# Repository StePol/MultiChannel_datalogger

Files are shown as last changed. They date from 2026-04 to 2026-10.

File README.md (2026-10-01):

# Multi-Channel DataLogger (RPi Pico)

Tento projekt predstavuje robustný amatérsky datalogger postavený na mikrokontroléri Raspberry Pi Pico. Zariadenie monitoruje teplotu, vlhkosť, analógové napätia, binárne vstupy a stav batérie.

## 🚀 Kľúčové vlastnosti

- **Meranie prostredia:** SHT4x pre teplotu a relatívnu vlhkosť.
- **Viacbodové meranie teploty:** viacero senzorov DS18B20 na zbernici OneWire.
- **Analógové vstupy:** dva ADC vstupy 0–3,3 V.
- **Monitorovanie batérie:** meranie napätia batérie cez samostatný ADC vstup; táto časť hardvéru a firmware je stále vo vývoji.
- **Binárne vstupy:** štyri digitálne vstupy pre sledovanie logických stavov.
- **Záznam dát:** ukladanie meraní vo formáte CSV na microSD kartu.
- **Používateľské rozhranie:** SSD1306 OLED displej a rotačný enkodér s tlačidlom.
- **Presný čas:** externý RTC DS3231 synchronizovaný s interným RTC Raspberry Pi Pico.

## 🛠 Hardvérová konfigurácia
| Komponent | Pin (GP) | Funkcia |
|---|---|---|
| I2C0 (SDA/SCL) | 8 / 9 | OLED, RTC DS3231, SHT4x |
| SPI0 (SCK/MOSI/MISO) | 18/19/16 | SD Karta |
| SD Card CS | 17 | Chip Select pre SD |
| OneWire (DS18B20) | 22 | Teplotné senzory |
| Rotačný enkodér | 12 (CLK), 13 (DT) | Ovládanie menu (IRQ) |
| Tlačidlo enkodéra | 15 | Prepínanie režimov (Pauza/REC/Test) |
| Binárne vstupy | 2, 3, 4, 5 | Digitálne vstupy (Pull-up) |
| ADC Vstupy | 26, 27 | Analógové meranie |
| Battery Monitor | 28 (ADC), 21 (CTRL) | Meranie batérie cez tranzistory |
| Stavová LED | 14 | Signalizácia zápisu a chýb |

## 📁 Štruktúra projektu

- `firmware/` — MicroPython firmware pre Raspberry Pi Pico
- `hardware/schematic/` — KiCad projekt, schéma, PCB a lokálne knižnice
- `hardware/enclosure/` — podklady pre mechanickú konštrukciu
- `docs/data/` — ukážkové namerané dáta
- `docs/datasheet/` — technická dokumentácia použitých komponentov

Podrobnosti o firmware sú v [`firmware/README.md`](firmware/README.md).

Dokumentácia hardvéru a KiCad projektu je v
[`hardware/schematic/README.md`](hardware/schematic/README.md).

## ⚙️ Prevádzkové režimy

- **PAUZA** — zariadenie vykonáva merania a zobrazuje aktuálne hodnoty, ale nezapisuje ich na SD kartu. Enkodérom je možné zvoliť režim alebo interval záznamu.
- **REC** — namerané údaje sa ukladajú na SD kartu v nastavenom intervale. Pre každý záznam sa vytvorí nový CSV súbor s názvom `YYYYMMDD_HHMMSS.csv`.
- **TEST** — umožňuje prechádzať pripojené DS18B20 senzory a zobrazovať ich ROM ID a aktuálnu teplotu.
- **SYNC RTC** — synchronizuje externý RTC DS3231 s aktuálnym časom interného RTC Raspberry Pi Pico.

Interval záznamu je možné nastaviť od 5 do 300 sekúnd v krokoch po 5 sekúnd.

Podrobný popis ovládania a režimov je v
[`firmware/README.md`](firmware/README.md).

## 💾 Formát dát (CSV)

Pri spustení režimu **REC** sa vytvorí nový CSV súbor s názvom odvodeným
od aktuálneho dátumu a času. Do rovnakého súboru sa zapisuje až do
ukončenia režimu REC.

Pevná časť CSV hlavičky je:

```text
Cas,SHT_T,SHT_H,A1,A2,BAT,BIN,B1,B2,B3,B4
```
Za ňou firmware pridá ROM ID jednotlivých detegovaných DS18B20 senzorov
ako ďalšie stĺpce.
Príklad nameraných dát je v adresári [`docs/data/`](docs/data/).

## 🛡 Stabilita záznamu

- **Obsluha enkodéra cez IRQ:** enkodér je spracovávaný pomocou prerušenia.
- **Zápis na SD kartu:** po zápise dát firmware používa `flush()` a `uos.sync()` na prenesenie dát do súborového systému.
- **Správa pamäte:** firmware pravidelne používa garbage collection (`gc.collect()`).

## 🔌 Zapojenie

Detailné elektrické zapojenie je dostupné v KiCad projekte v
[`hardware/schematic/`](hardware/schematic/).

### 1. I2C zbernica (GP8, GP9)

Na spoločnej I2C zbernici sú pripojené:

- OLED displej SSD1306
- RTC DS3231
- senzor teploty a vlhkosti SHT4x

SDA a SCL vyžadujú pull-up rezistory. Pri použití hotových modulov je
potrebné overiť, či ich už moduly obsahujú.

### 2. microSD karta (SPI0)

microSD karta komunikuje s Raspberry Pi Pico cez SPI0:

| Signál | GPIO |
|---|---:|
| SCK | GP18 |
| MOSI | GP19 |
| MISO | GP16 |
| CS | GP17 |

Komunikačné signály microSD karty pracujú s logickými úrovňami 3,3 V.

### 3. OneWire (GP22)

DS18B20: Všetky senzory paralelne (Data na GP22, VCC na 3.3V, GND).
Pull-up: Medzi GP22 a 3.3V musí byť odpor 4.7kΩ.

### 4. Monitorovanie batérie

Napätie batérie sa meria pomocou ADC na GP28, pričom GP21 slúži na
ovládanie meracieho obvodu.

Hardvérové zapojenie a spôsob merania batérie sú stále vo vývoji a môžu
sa zmeniť. Aktuálne zapojenie je zdokumentované v KiCad schéme.

### 5. Ovládacie prvky

- **Enkodér:** CLK na GP12, DT na GP13; 10 nF kondenzátory slúžia na filtráciu zákmitov.
- **Tlačidlo enkodéra:** GP15, aktívne zopnutím proti GND s interným pull-up rezistorom.
- **Stavová LED:** GP14 cez 220 Ω rezistor.

## 📄 Licencia

Tento projekt je licencovaný pod [GNU GPL v3](LICENSE).

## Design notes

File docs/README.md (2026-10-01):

# Documentation

This directory contains supplementary documentation and example data for the
Multi-Channel DataLogger.

## Contents

| Directory | Description |
|---|---|
| `data/` | Example measurement data recorded by the datalogger |
| `datasheet/` | Datasheets and technical notes for hardware components |

## Measurement Data

The `data/` directory contains example CSV files generated by the firmware.
These files can be used to verify the data format or for testing data-processing
and visualization tools.

The current firmware records:

- SHT4x temperature and relative humidity
- multiple DS18B20 temperature sensors
- two analog inputs
- battery voltage
- four digital inputs

For the current CSV format and firmware operation, see
[`../firmware/README.md`](../firmware/README.md).

## Hardware Documentation

Component datasheets and related technical notes are stored in
[`datasheet/`](datasheet/).

The KiCad schematic and project-specific hardware documentation are located in
[`../hardware/schematic/`](../hardware/schematic/).

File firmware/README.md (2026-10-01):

# Firmware

This directory contains the software running on the Raspberry Pi Pico (RP2040).

## Hardware
- **Microcontroller:** Raspberry Pi Pico
- **Processor:** RP2040 (dual-core ARM Cortex-M0+)
- **Runtime:** MicroPython

## Development Environment
- **IDE:** Thonny
- **Language:** MicroPython

## Requirements
- Raspberry Pi Pico with MicroPython firmware installed
- Thonny IDE — [download here](https://thonny.org)

## Installation
1. Install MicroPython on the Pico:
   - Hold **BOOTSEL** button and connect Pico via USB
   - Copy the MicroPython `.uf2` file to the Pico drive
   - Pico restarts automatically
2. Open Thonny
3. Go to **Run → Select interpreter → MicroPython (Raspberry Pi Pico)**
4. Copy `.py` files to the Pico via Thonny

## Usage
- Open `main.py` in Thonny and click **Run**
- `main.py` is executed automatically on power-up

## Measured Parameters
- SHT4x temperature and relative humidity
- Multiple DS18B20 temperature sensors
- Two analog voltage inputs
- Battery voltage
- Four digital inputs

## Data Output
- CSV logging to microSD card
- Serial diagnostic output over USB
- Measurement status on SSD1306 OLED
- Logging interval selectable from 5 to 300 seconds
- CSV files use the timestamp format `YYYYMMDD_HHMMSS.csv`

## Operating Modes

The logger is controlled using the rotary encoder and its push button.

- **PAUZA** — measurements are displayed, but data is not written to the SD card.
- **REC** — measurements are periodically written to a CSV file.
- **TEST** — displays connected DS18B20 sensors, their ROM IDs and temperatures.
- **SYNC** — synchronizes the external DS3231 RTC with the current internal RTC time.

While in PAUZA mode, the rotary encoder selects `SyncRTC`, `TEST`, or a
logging interval from 5 to 300 seconds in 5-second steps.

## CSV Format

Each recording creates a new timestamped CSV file.

The fixed columns are:

```text
Cas,SHT_T,SHT_H,A1,A2,BAT,BIN,B1,B2,B3,B4
```

The ROM ID of each detected DS18B20 sensor is appended to the header as an
additional column.

An example recording is available in `../docs/data/`.

## Firmware Files

| File | Description |
|---|---|
| `main.py` | Main application and measurement loop |
| `ds3231.py` | DS3231 RTC driver |
| `sdcard.py` | microSD card driver |
| `sht4x.py` | SHT4x temperature/humidity driver |
| `ssd1306.py` | SSD1306 OLED driver |
| `TimeSet.py` | RTC utility |
| `TimeSyncPC.py` | RTC synchronization utility |

## Development Status

The battery measurement circuit and the corresponding firmware are still
under development and may change.

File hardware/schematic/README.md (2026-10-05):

# MultiChannel Datalogger – Hardware

This directory contains the KiCad hardware design files for the
MultiChannel Datalogger.

## KiCad version

The project is maintained with **KiCad 10**.

Open the project using:

`MultiChannel_datalogger.kicad_pro`

Do not open only the `.kicad_sch` file when working on the complete project.

## Project files

| File / Directory | Description |
|---|---|
| `MultiChannel_datalogger.kicad_pro` | KiCad project file |
| `MultiChannel_datalogger.kicad_sch` | Electrical schematic |
| `MultiChannel_datalogger.kicad_pcb` | PCB design |
| `MultiChannel_datalogger.pdf` | PDF export of the schematic |
| `MultiChannel_datalogger.csv` | Component/BOM export |
| `ADS1256_J3.md` | Tested ADS1256 24-bit ADC connection via J3 |
| `sym-lib-table` | Project symbol library configuration |
| `fp-lib-table` | Project footprint library configuration |
| `libraries/` | Project-specific symbols and footprints |

## Project libraries

Project-specific KiCad libraries are stored locally in the `libraries/`
directory so that the project does not depend on absolute paths on the
developer's computer.

The library tables use `${KIPRJMOD}` relative paths.

Currently included:

- Raspberry Pi / RP2040 symbol library
- Raspberry Pi Pico footprint
- RP2040 QFN-56 footprint
- HC49-US crystal footprint

## Portability

The repository is intended to contain all project-specific KiCad files
required to open the hardware design on another computer after cloning
the repository.

Standard symbols and footprints supplied with KiCad may still use the
standard KiCad libraries.

KiCad user-specific files, lock files, history and automatic backups are
excluded from Git.

## PCB status

The PCB project file is included, but the PCB layout has not yet been
designed.

## Generated files

`MultiChannel_datalogger.pdf` and `MultiChannel_datalogger.csv` are
generated from the schematic and should be updated when the schematic
changes significantly.

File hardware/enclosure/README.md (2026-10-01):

# Enclosure

This directory is reserved for the mechanical design of the
Multi-Channel DataLogger enclosure.

## Status

The enclosure has not been designed yet.

Mechanical dimensions, connector locations, display and control placement,
mounting points, and manufacturing method will be defined after the hardware
layout is sufficiently finalized.

## Planned Contents

The directory may later contain:

- source CAD files
- STEP or other exchange-format models
- STL files for 3D printing
- drawings with mechanical dimensions
- assembly documentation
- renders or photographs of the completed enclosure

## Design Considerations

The enclosure design should take into account:

- Raspberry Pi Pico and main PCB dimensions
- OLED display visibility
- rotary encoder and push-button access
- microSD card access
- sensor and measurement connectors
- USB access
- battery placement
- ventilation where required
- mounting and service access

Specific CAD software, manufacturing technology, materials, and print settings
will be selected when the enclosure design begins.

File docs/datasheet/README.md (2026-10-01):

# Datasheets

This directory contains component datasheets and technical notes used during
development of the Multi-Channel DataLogger.

## Sensors and RTC

| File | Component |
|---|---|
| `DS18B20.PDF` | DS18B20 digital temperature sensor |
| `DS3231.PDF` | DS3231 real-time clock |
| `SHT4X.PDF` | SHT4x temperature and humidity sensor |

## Battery Measurement

| File | Description |
|---|---|
| `MeranieNapatiaLiIonBaterie.md` | Project notes for Li-ion battery voltage measurement |
| `2N7000_BS170.PDF` | Vishay Siliconix datasheet covering the BS170 N-channel MOSFET used as Q2 |

The battery measurement circuit is still under development. Files in this
section are retained as design references and should not be interpreted as the
final component selection.

The current electrical design is documented in the KiCad project under
[`../../hardware/schematic/`](../../hardware/schematic/).

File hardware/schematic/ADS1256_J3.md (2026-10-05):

# ADS1256 connection via J3

This document describes the tested connection of an external ADS1256
24-bit ADC module to the Multi-Channel DataLogger through the existing
J3 Sensor Input Connector.

## Connection

| J3 / Raspberry Pi Pico | ADS1256 | Function |
|---|---|---|
| 5V | VCC | Module power supply |
| GND | GND | Common ground |
| GP2 | SCLK | SPI clock |
| GP3 | DIN | SPI MOSI |
| GP4 | DOUT | SPI MISO |
| GP5 | CS | Chip select |
| GP26 | DRDY | Data ready |
| GP27 | RST | Hardware reset |
| 3V3 | PDWN | Keeps ADS1256 active |

## Unused J3 signal

GP22 is intentionally not used for the ADS1256.

GP22 is used by the existing 1-Wire bus and has a 4.7 kOhm pull-up
resistor to 3.3 V.

## ADS1256 module notes

- ADS1256 VCC is powered from the J3 5V output.
- PDWN is tied to J3 3V3 and is not controlled by firmware.
- The module pin marked `2.5V` is not connected.
- SPI communication is implemented in software because the selected
  J3 GPIO combination does not form a complete RP2040 hardware SPI bus.

## Verified communication

The connection was tested with MicroPython.

Register readout:

```text
STATUS = 0x30
MUX    = 0x01
ADCON  = 0x20
DRATE  = 0xF0
IO     = 0xE1

CHIP ID = 0x3
```
The returned CHIP ID \ 0x3` confirms successful communication with the ADS1256.`

## Final pin assignment
```text
J3                  ADS1256
--------------------------------
5V       ---------> VCC
GND      ---------> GND
GP2      ---------> SCLK
GP3      ---------> DIN
GP4      <--------- DOUT
GP5      ---------> CS
GP26     <--------- DRDY
GP27     ---------> RST
3V3      ---------> PDWN
GP22                not used
2.5V                not connected
```

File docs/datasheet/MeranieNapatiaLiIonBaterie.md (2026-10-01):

# Meranie napätia Li-ion batérie

> **Stav:** Rozpracované. Zapojenie aj firmware pre meranie batérie sa môžu
> ešte zmeniť.

Aktuálny návrh používa spínaný napäťový delič, aby nebol delič trvalo
pripojený k batérii.

## Aktuálne komponenty

Podľa aktuálnej KiCad schémy sú použité:

- **Q1 — BSS84** — P-MOSFET
- **Q2 — BS170** — N-MOSFET
- **R3 — 10 kΩ** — spodný rezistor napäťového deliča
- **R4 — 10 kΩ** — horný rezistor napäťového deliča
- **R5 — 1 kΩ** — sériový rezistor gate Q2
- **R6 — 10 kΩ** — pull-down gate Q2
- **R7 — 10 kΩ** — pull-up gate Q1
- **GP21** — riadenie meracieho obvodu
- **GP28 / ADC2** — meranie napätia batérie

## Princíp zapojenia

P-MOSFET BSS84 pripája napäťový delič k batérii iba počas merania.
Jeho gate je ovládaný pomocou N-MOSFETu BS170.

### Vypnutý stav

GP21 je v stave LOW. BS170 je vypnutý a gate BSS84 je držaný na úrovni
napätia batérie. BSS84 je zatvorený a napäťový delič nie je aktívny.

### Meranie

GP21 sa nastaví na HIGH. BS170 sa otvorí a stiahne gate BSS84 smerom
k GND. BSS84 sa otvorí a pripojí napäťový delič k batérii.

Napätie zo stredu deliča sa následne meria pomocou ADC na GP28.
R4 a R3 majú hodnotu 10 kΩ a vytvárajú napäťový delič s pomerom 1:1.
Napätie na ADC je preto približne polovica napätia batérie. Pri napätí
batérie 4,2 V je na ADC približne 2,1 V.

## Aktuálna implementácia vo firmware

Aktuálny firmware používa tento princíp:

```python
Batt_ctrl_pin.value(1)
v_bat = round((adc_bat.read_u16() * 3.3) / 65535, 2) * 2
Batt_ctrl_pin.value(0)
```

Výpočet momentálne predpokladá napäťový delič s pomerom 1:1.

## Ďalší vývoj

Pred finálnou verziou je potrebné overiť najmä:

- hodnoty rezistorov napäťového deliča
- presnosť merania ADC
- stabilizačný čas po zapnutí meracieho obvodu
- skutočný odber vo vypnutom stave
- kalibráciu meraného napätia
- správanie obvodu v celom rozsahu napätia Li-ion článku

Autoritatívnym zdrojom aktuálneho elektrického zapojenia je KiCad schéma v
[`../../hardware/schematic/`](../../hardware/schematic/).

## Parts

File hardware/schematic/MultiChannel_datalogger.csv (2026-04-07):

Source: | /home/stepol/Dokumenty/KICAD/SIGEN/MultiChannel_datalogger/MultiChannel_datalogger.kicad_sch
Date: | Tue 07 Apr 2026 15:12:05 CEST
Tool: | Eeschema 6.0.11-2627ca5db0~126~ubuntu20.04.1
Generator: | /usr/share/kicad/plugins/bom_csv_grouped_by_value.py
Component Count: | 34
Individual Components:
Item | Qty | Reference(s) | Value | LibPart | Footprint | Datasheet
 |  | Brd1 | SSD1306 | SSD1306-128x64_OLED:SSD1306
 |  | BT1 | 3V | Device:Battery_Cell |  | ~
 |  | BT2 | 3V7 - 18650 | Device:Battery_Cell |  | ~
 |  | C1 | 100nF | Device:C |  | ~
 |  | C2 | 10n | Device:C |  | ~
 |  | C3 | 100nF | Device:C |  | ~
 |  | C4 | 10n | Device:C |  | ~
 |  | C5 | 470uF | Device:C_Polarized |  | ~
 |  | C6 | 470uF | Device:C_Polarized |  | ~
 |  | C7 | 100nF | Device:C |  | ~
 |  | C8 | 100nF | Device:C |  | ~
 |  | D1 | LED | Device:LED |  | ~
 |  | J1 | Conn_01x04_Male | Connector:Conn_01x04_Male |  | ~
 |  | J2 | Conn_01x04_Female | Connector:Conn_01x04_Female |  | ~
 |  | J3 | Conn_02x08_Top_Bottom | Connector_Generic:Conn_02x08_Top_Bottom |  | ~
 |  | J4 | Conn_01x03_Male | Connector:Conn_01x03_Male |  | ~
 |  | J5 | Micro_SD_Card | Connector:Micro_SD_Card |  | http://katalog.we-online.de/em/datasheet/693072010801.pdf
 |  | J6 | Conn_01x03_Female | Connector:Conn_01x03_Female |  | ~
 |  | Q1 | BSS84 | Transistor_FET:BSS84 | Package_TO_SOT_SMD:SOT-23 | http://assets.nexperia.com/documents/data-sheet/BSS84.pdf
 |  | Q2 | BS170 | Transistor_FET:BS170 | Package_TO_SOT_THT:TO-92_Inline | https://www.onsemi.com/pub/Collateral/BS170-D.PDF
 |  | R1 | 1k | Device:R |  | ~
 |  | R2 | 3k3 | Device:R |  | ~
 |  | R3 | 10k | Device:R |  | ~
 |  | R4 | 10k | Device:R |  | ~
 |  | R5 | 1k | Device:R |  | ~
 |  | R6 | 10k | Device:R |  | ~
 |  | R7 | 10k | Device:R |  | ~
 |  | SW1 | RotaryEncoder_Switch | Device:RotaryEncoder_Switch |  | ~
 |  | SW2 | SW_SPDT_MSM | Switch:SW_SPDT_MSM |  | ~
 |  | U1 | DS3231MZ | Timer_RTC:DS3231MZ | Package_SO:SOIC-8_3.9x4.9mm_P1.27mm | http://datasheets.maximintegrated.com/en/ds/DS3231M.pdf
 |  | U2 | SHT4x | Sensor_Humidity:SHT4x | Sensor_Humidity:Sensirion_DFN-4_1.5x1.5mm_P0.8mm_SHT4x_NoCentralPad | https://sensirion.com/media/documents/33FD6951/624C4357/Datasheet_SHT4x.pdf
 |  | U3 | Pico | MCU_RaspberryPi_and_Boards:Pico | RPi_Pico:RPi_Pico_SMD_TH
 |  | U4 | DS18B20 | Sensor_Temperature:DS18B20 | Package_TO_SOT_THT:TO-92_Inline | http://datasheets.maximintegrated.com/en/ds/DS18B20.pdf
 |  | U5 | 18650_Boost_TypeC_Module | :18650_Boost_TypeC_Module_1 | 18650_Boost_Module:18650_Boost_TypeC_Module
Collated Components:
Item | Qty | Reference(s) | Value | LibPart | Footprint | Datasheet
1 | 1 | Brd1 | SSD1306 | SSD1306-128x64_OLED:SSD1306
2 | 1 | BT1 | 3V | Device:Battery_Cell |  | ~
3 | 1 | BT2 | 3V7 - 18650 | Device:Battery_Cell |  | ~
4 | 4 | C1, C3, C7, C8 | 100nF | Device:C |  | ~
5 | 2 | C2, C4 | 10n | Device:C |  | ~
6 | 2 | C5, C6 | 470uF | Device:C_Polarized |  | ~
7 | 1 | D1 | LED | Device:LED |  | ~
8 | 1 | J1 | Conn_01x04_Male | Connector:Conn_01x04_Male |  | ~
9 | 1 | J2 | Conn_01x04_Female | Connector:Conn_01x04_Female |  | ~
10 | 1 | J3 | Conn_02x08_Top_Bottom | Connector_Generic:Conn_02x08_Top_Bottom |  | ~
11 | 1 | J4 | Conn_01x03_Male | Connector:Conn_01x03_Male |  | ~
12 | 1 | J5 | Micro_SD_Card | Connector:Micro_SD_Card |  | http://katalog.we-online.de/em/datasheet/693072010801.pdf
13 | 1 | J6 | Conn_01x03_Female | Connector:Conn_01x03_Female |  | ~
14 | 1 | Q1 | BSS84 | Transistor_FET:BSS84 | Package_TO_SOT_SMD:SOT-23 | http://assets.nexperia.com/documents/data-sheet/BSS84.pdf
15 | 1 | Q2 | BS170 | Transistor_FET:BS170 | Package_TO_SOT_THT:TO-92_Inline | https://www.onsemi.com/pub/Collateral/BS170-D.PDF
16 | 2 | R1, R5 | 1k | Device:R |  | ~
17 | 1 | R2 | 3k3 | Device:R |  | ~
18 | 4 | R3, R4, R6, R7 | 10k | Device:R |  | ~
19 | 1 | SW1 | RotaryEncoder_Switch | Device:RotaryEncoder_Switch |  | ~
20 | 1 | SW2 | SW_SPDT_MSM | Switch:SW_SPDT_MSM |  | ~
21 | 1 | U1 | DS3231MZ | Timer_RTC:DS3231MZ | Package_SO:SOIC-8_3.9x4.9mm_P1.27mm | http://datasheets.maximintegrated.com/en/ds/DS3231M.pdf
22 | 1 | U2 | SHT4x | Sensor_Humidity:SHT4x | Sensor_Humidity:Sensirion_DFN-4_1.5x1.5mm_P0.8mm_SHT4x_NoCentralPad | https://sensirion.com/media/documents/33FD6951/624C4357/Datasheet_SHT4x.pdf
23 | 1 | U3 | Pico | MCU_RaspberryPi_and_Boards:Pico | RPi_Pico:RPi_Pico_SMD_TH
24 | 1 | U4 | DS18B20 | Sensor_Temperature:DS18B20 | Package_TO_SOT_THT:TO-92_Inline | http://datasheets.maximintegrated.com/en/ds/DS18B20.pdf
25 | 1 | U5 | 18650_Boost_TypeC_Module | :18650_Boost_TypeC_Module_1 | 18650_Boost_Module:18650_Boost_TypeC_Module

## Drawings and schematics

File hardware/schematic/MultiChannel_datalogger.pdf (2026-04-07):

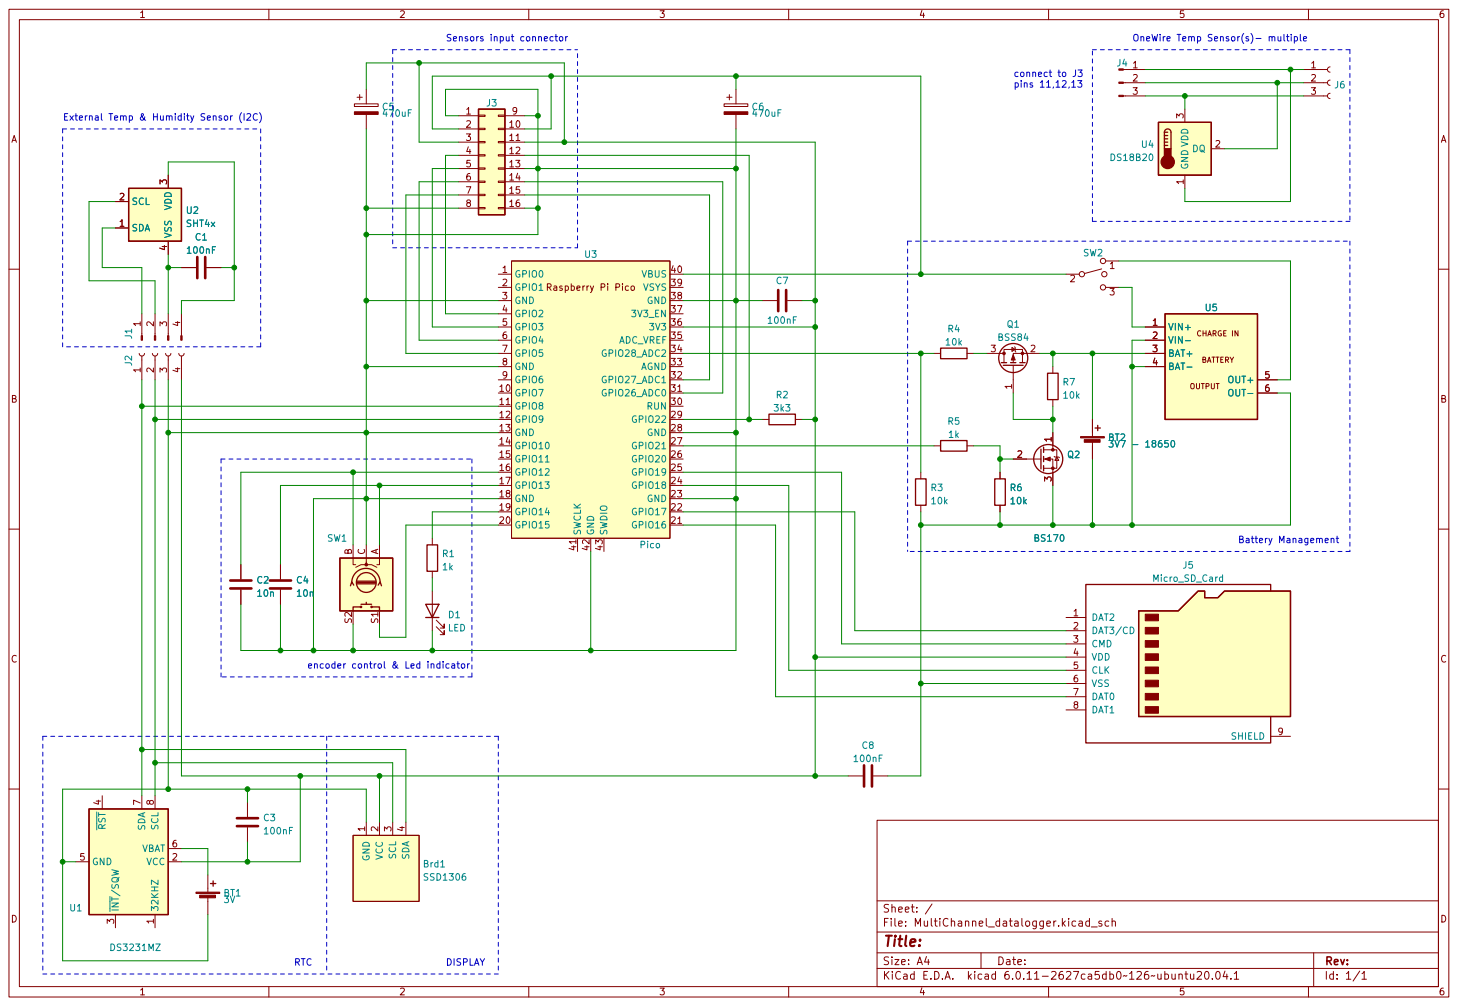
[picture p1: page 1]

5 | | 13
6 | | 14
7 | | 15
8 | | 16

BATTERY CHARGE IN OUTPUT VIN+

Id: 1/1 Title: File: MultiChannel_datalogger.kicad_sch Sheet: /

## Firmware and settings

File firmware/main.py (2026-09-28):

import machine, onewire, ds18x20, sdcard, uos, ssd1306, time, ds3231, sht4x, ubinascii, gc

# --- KONFIGURÁCIA ---
TLACITKO_PIN = machine.Pin(15, machine.Pin.IN, machine.Pin.PULL_UP)
LED_EXT = machine.Pin(14, machine.Pin.OUT)
CS_SD = machine.Pin(17)
bin_vstupy = [machine.Pin(p, machine.Pin.IN, machine.Pin.PULL_UP) for p in (2, 3, 4, 5)]
pin_clk = machine.Pin(12, machine.Pin.IN, machine.Pin.PULL_UP)
pin_dt = machine.Pin(13, machine.Pin.IN, machine.Pin.PULL_UP)
adc1, adc2 = machine.ADC(26), machine.ADC(27)
adc_bat = machine.ADC(28)
Batt_ctrl_pin = machine.Pin(21, machine.Pin.OUT)  # Ovládanie cez GP21

# --- INICIALIZÁCIA ---
i2c = machine.I2C(0, sda=machine.Pin(8), scl=machine.Pin(9))
spi = machine.SPI(0, sck=machine.Pin(18), mosi=machine.Pin(19), miso=machine.Pin(16))
oled = ssd1306.SSD1306_I2C(128, 64, i2c)
oled.write_cmd(0xA1); oled.write_cmd(0xC8)
rtc_ext = ds3231.DS3231(i2c)
senzor_sht = sht4x.SHT4X(i2c)
ds_sensor = ds18x20.DS18X20(onewire.OneWire(machine.Pin(22)))

# --- SYNC A SD ---
try:
    t = rtc_ext.get_time()
    machine.RTC().datetime((t[0], t[1], t[2], 0, t[3], t[4], t[5], 0))
except: print("RTC Sync Fail")

sd_ready = False

def mount_sd():
    global sd_ready
    try:
        sd_inst = sdcard.SDCard(spi, CS_SD)
        vfs = uos.VfsFat(sd_inst)
        uos.mount(vfs, "/sd")
        sd_ready = True
        print("SD karta pripravena.")
    except:
        sd_ready = False

def check_sd():
    """Detekcia vytiahnutia/vloženia karty — volať len v PAUZA móde."""
    global sd_ready
    if sd_ready:
        try:
            # Pokus o listovanie root adresára — menej agresívne ako zápis
            uos.listdir("/sd")
        except:
            try: uos.umount("/sd")
            except: pass
            sd_ready = False
            print("SD karta vytiahnutá.")
    else:
        try:
            sd_inst = sdcard.SDCard(spi, CS_SD)
            vfs = uos.VfsFat(sd_inst)
            uos.mount(vfs, "/sd")
            sd_ready = True
            print("SD karta pripravená.")
        except:
            sd_ready = False

mount_sd()

# --- PREMENNÉ ---
mode = "PAUZA"
# interval: -1 = SyncRTC, 0 = TEST, 5-300 = interval zápisu v sekundách
interval = 60
test_index = 0
last_btn = 1
posledny_prevod_ds = 0
filename = ""
roms = ds_sensor.scan()
ds_v = [0.0] * len(roms)
st, sh = 0.0, 0.0
posledny_zapis_ms = time.ticks_ms()
loop_timer = time.ticks_ms()
sd_check_timer = time.ticks_ms()
SD_CHECK_INTERVAL = 5000  # Kontrola SD karty každých 5 sekúnd

# --- ENKODÉR CEZ PRERUŠENIA ---
last_clk_state = pin_clk.value()

def encoder_handler(pin):
    global interval, test_index, mode, last_clk_state

    current_clk_state = pin_clk.value()
    # Vyhodnotíme len pri zmene stavu CLK
    if current_clk_state != last_clk_state:
        dt_state = pin_dt.value()

        # Smer otáčania: ak sa CLK líši od DT, ideme jedným smerom, inak druhým
        direction = 1 if dt_state != current_clk_state else -1

        if mode == "PAUZA":
            # Menu: SyncRTC (-1) -> TEST (0) -> 5s -> 10s -> ... -> 300s
            if direction == -1:
                if interval > 5:    interval -= 5
                elif interval == 5: interval = 0    # 5s -> TEST
                elif interval == 0: interval = -1   # TEST -> SyncRTC
            else:
                if interval == -1:   interval = 0   # SyncRTC -> TEST
                elif interval == 0:  interval = 5   # TEST -> 5s
                elif interval < 300: interval += 5

        elif mode == "TEST" and roms:
            # Prepínanie senzorov v TEST móde
            test_index = (test_index + direction) % len(roms)

        last_clk_state = current_clk_state

# Nastavenie prerušení na oboch hranách CLK
pin_clk.irq(trigger=machine.Pin.IRQ_RISING | machine.Pin.IRQ_FALLING, handler=encoder_handler)

if roms: ds_sensor.convert_temp()

# --- HLAVNÁ SLUČKA ---
while True:
    # 1. OPTIMALIZÁCIA PAMÄTE
    gc.collect()

    # Udržujeme stabilnú slučku cca 20Hz (50ms)
    if time.ticks_diff(time.ticks_ms(), loop_timer) < 50:
        continue
    loop_timer = time.ticks_ms()

    lt = time.localtime()
    cas_s = "{:02d}:{:02d}:{:02d}".format(lt[3], lt[4], lt[5])

    # 2. KONTROLA SD — len v PAUZA móde
    if mode == "PAUZA":
        if time.ticks_diff(time.ticks_ms(), sd_check_timer) > SD_CHECK_INTERVAL:
            check_sd()
            sd_check_timer = time.ticks_ms()

    # 3. OVLÁDANIE TLAČIDLA
    curr_btn = TLACITKO_PIN.value()
    if last_btn == 1 and curr_btn == 0:
        time.sleep_ms(50)
        if mode == "PAUZA":
            roms = ds_sensor.scan()
            ds_v = [0.0] * len(roms)
            if interval == -1:
                # Prechod do SYNC módu
                mode = "SYNC"
            elif interval == 0:
                # Prechod do TEST módu
                mode = "TEST"; test_index = 0
            else:
                # Prechod do REC módu — vytvorí nový súbor s časovou pečiatkou
                mode = "REC"
                posledny_zapis_ms = time.ticks_ms()
                filename = "/sd/{:04d}{:02d}{:02d}_{:02d}{:02d}{:02d}.csv".format(*lt)
        else:
            mode = "PAUZA"
        LED_EXT.value(1); time.sleep_ms(100); LED_EXT.value(0)
    last_btn = curr_btn

    # 4. MERANIE
    try: st, sh = senzor_sht.measurements()
    except: st, sh = -99.9, -99.9

    Batt_ctrl_pin.value(1)        # Otvorí BS170 -> zopne BSS84
    v1 = round((adc1.read_u16() * 3.3) / 65535, 2)
    v2 = round((adc2.read_u16() * 3.3) / 65535, 2)
    v_bat = round((adc_bat.read_u16() * 3.3) / 65535, 2) * 2
    Batt_ctrl_pin.value(0)        # Okamžite odpojí delič (nulová spotreba)

    bin_s = "".join(["0" if p.value() == 0 else "1" for p in bin_vstupy])

    if roms and time.ticks_diff(time.ticks_ms(), posledny_prevod_ds) > 800:
        try:
            ds_v = [round(ds_sensor.read_temp(r), 2) for r in roms]
            ds_sensor.convert_temp()
            posledny_prevod_ds = time.ticks_ms()
        except: pass

    # 5. DISPLEJ A LOGIKA ZÁPISU
    oled.fill(0)
    oled.text(cas_s, 64, 0)

    if mode == "PAUZA":
        oled.text("STOP", 0, 0)
        # Zobrazenie aktuálne zvolenej položky menu
        if interval == -1:  label = "SyncRTC"
        elif interval == 0: label = "TEST"
        else:               label = "{}s".format(interval)
        oled.text("Int: {}".format(label), 0, 12)

    elif mode == "SYNC":
        # Synchronizácia RTC podľa interných hodín Pico (nastavených Thonny pri spustení)
        oled.text("SYNC RTC", 0, 0)
        oled.text("Synchronizujem...", 0, 24)
        oled.show()
        try:
            t = time.localtime()
            rtc_ext.datetime((t[0], t[1], t[2], t[3], t[4], t[5], t[6]))
            machine.RTC().datetime((t[0], t[1], t[2], 0, t[3], t[4], t[5], 0))
            print("------------------------------------------")
            print("RTC zosynchronizovany s PC!")
            print("Aktuálny čas: {:02d}:{:02d}:{:02d}".format(t[3], t[4], t[5]))
            print("------------------------------------------")
            oled.fill(0)
            oled.text("SYNC RTC", 0, 0)
            oled.text("OK!", 0, 24)
            oled.text("{:02d}:{:02d}:{:02d}".format(t[3], t[4], t[5]), 0, 40)
            oled.show()
        except Exception as e:
            print("SYNC CHYBA:", e)
            oled.fill(0)
            oled.text("SYNC CHYBA!", 0, 24)
            oled.show()
        time.sleep_ms(2000)
        mode = "PAUZA"

    elif mode == "TEST":
        oled.text("TEST", 0, 0)
        if roms:
            fa = ubinascii.hexlify(roms[test_index]).decode()
            oled.text("Senzor: {}/{}".format(test_index + 1, len(roms)), 0, 12)
            oled.text("ID: {}".format(fa[:8]), 0, 24)
            oled.text("    {}".format(fa[8:]), 0, 34)
            oled.text("Teplota: {}C".format(ds_v[test_index] if test_index < len(ds_v) else "--"), 0, 48)
        else:
            oled.text("Ziadne senzory!", 0, 24)

    elif mode == "REC":
        if int(time.time()) % 2: oled.text("REC", 0, 0)

        # Výpočet času do ďalšieho zápisu
        ms_od_zapisu = time.ticks_diff(time.ticks_ms(), posledny_zapis_ms)
        sek_do = max(0, interval - (ms_od_zapisu // 1000))
        oled.text("Ct: {}s".format(int(sek_do)), 0, 12)

        if ms_od_zapisu >= (interval * 1000):
            # --- TERMINÁL VÝPIS ---
            print("\n" + "=" * 50)
            print("ZAPIS [{}] SHT:{:.1f}C {:.1f}% ADC:{}V {}V BIN:{}".format(
                cas_s, st, sh, v1, v2, bin_s))
            for i, r in enumerate(roms):
                print("  DS #{}: [{}] -> {}C".format(i + 1, ubinascii.hexlify(r).decode(), ds_v[i]))

            # --- ZÁPIS NA SD ---
            if sd_ready:
                try:
                    # Zisťujeme, či súbor existuje (ak nie, musíme zapísať hlavičku)
                    try: uos.stat(filename); subor_existuje = True
                    except: subor_existuje = False

                    with open(filename, "a") as f:
                        # Ak súbor neexistoval, zapíšeme hlavičku s ID senzormi
                        if not subor_existuje:
                            ids = ",".join([ubinascii.hexlify(r).decode() for r in roms])
                            f.write("Cas,SHT_T,SHT_H,A1,A2,BAT,BIN,B1,B2,B3,B4,{}\n".format(ids))
                            print("-> Vytvorena hlavicka s ID.")
                        data_row = "{},{:.2f},{:.1f},{:.2f},{:.2f},{:.2f},{},{},{}\n".format(
                            cas_s, st, sh, v1, v2, v_bat, bin_s,
                            ",".join([c for c in bin_s]),
                            ",".join(map(str, ds_v))
                        )
                        f.write(data_row)
                        f.flush()
                        uos.sync()
                    print("-> Ulozene na SD: " + filename)
                except Exception as e:
                    print("-> CHYBA ZAPISU:", e)
                    sd_ready = False

            LED_EXT.value(1); time.sleep_ms(50); LED_EXT.value(0)
            posledny_zapis_ms = time.ticks_ms()

    # 6. SPODNÝ RIADOK DISPLEJA — merania (nie v TEST a SYNC móde)
    if mode not in ("TEST", "SYNC"):
        oled.text("SHT: {:.1f}C {:.0f}%".format(st, sh), 0, 24)
        oled.text("ADC: {:.2f}V {:.2f}V".format(v1, v2), 0, 34)
        oled.text("DS: {} BIN: {}".format(len(roms), bin_s), 0, 44)
        try:
            if sd_ready:
                fs = uos.statvfs("/sd")
                oled.text("SD:{:.2f}GB".format((fs[0] * fs[3]) / (1024 ** 3)), 0, 54)
            else:
                oled.text("SD:none", 0, 54)
        except:
            oled.text("SD:err", 0, 54)
        oled.text(">{:.2f}V".format(v_bat), 80, 54)

    oled.show()
    time.sleep_ms(10)

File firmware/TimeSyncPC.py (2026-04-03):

import machine
import ds3231
import time

# Inicializácia I2C pre RTC
i2c = machine.I2C(0, sda=machine.Pin(8), scl=machine.Pin(9))
rtc_ext = ds3231.DS3231(i2c)

def sync_rtc_from_pc():
    # Thonny pri spustení nastaví interné hodiny Pico podľa PC
    t = time.localtime()
    
    # Formát pre rtc.datetime: (rok, mesiac, deň, hodina, minúta, sekunda, deň_v_týždni)
    # t[6] je deň v týždni (0-6)
    rtc_ext.datetime((t[0], t[1], t[2], t[3], t[4], t[5], t[6]))
    
    print("------------------------------------------")
    print("RTC modul bol zosynchronizovaný s PC!")
    print("Aktuálny čas: {:02d}:{:02d}:{:02d}".format(t[3], t[4], t[5]))
    print("------------------------------------------")

sync_rtc_from_pc()

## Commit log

2026-04-03 Expand README with pinout and module connection details
    Added detailed pinout and wiring instructions for Raspberry Pi Pico.
2026-04-03 Log DS sensor readings in terminal output
    Added logging for DS sensors with their readings.
2026-04-04 Add README for schematic directory
2026-04-04 Add README for enclosure design and printing details
2026-04-04 Revise README for Raspberry Pi Pico and setup instructions
    Updated README to reflect changes for Raspberry Pi Pico and added hardware and development environment sections.
2026-04-04 Add Meranie Napatia Li-Ion Baterie datasheet
    Added a datasheet for the Meranie Napatia Li-Ion Baterie, including wiring diagrams, operational principles, and example MicroPython code for battery voltage measurement.
2026-04-04 Revise wiring diagram and MicroPython code example
    Updated wiring diagram and MicroPython example for P-MOSFET and N-MOSFET configuration. Improved clarity on resistor connections and voltage measurement process.
2026-04-04 Fix code formatting in battery voltage measurement example
    Updated code example for battery voltage measurement in MicroPython.
2026-04-08 Fix SD card hot-swap detection in PAUZA mode
    [main.py]
2026-09-28 Complete portable KiCad project
    [MultiChannel_datalogger.kicad_pcb]
2026-09-28 Migrate SSD1306 symbol library to KiCad format
2026-09-28 Migrate schematic to KiCad 10 format
    [MultiChannel_datalogger.kicad_sch]
2026-09-28 Fix Raspberry Pi Pico footprint library reference
    [MultiChannel_datalogger.kicad_sch]
2026-09-28 Add battery voltage to CSV logging
2026-10-01 Update enclosure documentation
2026-10-01 Fix battery voltage measurement circuit
    [MultiChannel_datalogger.kicad_sch]
2026-10-16 Select ADS1256 On or Off from encoder menu while logging is stopped
2026-10-19 Document Pico verification of ADS1256 encoder switching
2026-10-19 Add encoder-selectable sample averaging for ADS1256 channels
2026-10-25 Reorder main menu and rename sensor test to 1WIRE
2026-11-07 Add ADS1256 raw, impedance and divider modes with serial controls
    Implement START, STOP, STATUS, HELP and guarded RESET commands. Persist divider and input settings, add coverage, document Pico verification and configure MicroPython editor stubs. All 54 host tests pass.
2026-11-07 Add standalone AI guide for long-term measurement
    Document device operation, serial commands, input modes, divider calculations, CSV interpretation and experiment planning. Link the portable guide from project and firmware documentation.
